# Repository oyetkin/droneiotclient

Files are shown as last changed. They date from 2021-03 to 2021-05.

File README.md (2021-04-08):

# droneiotclient

## Overview

This is the client end of a system designed to measure sensor data from a set of "Data Loggers" deployed in the field, retrieve the sensor data from a "Data Collector" device, and then process and use the data. The system contains 4 main items:

1. esp32_sleep: This code is for the Data Logger. The device is meant to include an ESP32 microcontroller, an SSD1306 display screen, a BME280 temperature/pressure/humidity sensor, and an IR receiver. The device consumes very low power so that it can last for weeks on battery power alone. It wakes up on a configurable interval to collect data, stores that data, and goes back to sleep. When the Data Collector device sends an IR signal to the device, it wakes up, sends its data using point-to-point WiFi (ESP-Now), and goes back to sleep.
The device also has a second Wifi mode, which can be toggled using a push button. In this mode, the device wakes up, connects to a WiFi network, and posts its data to a server.  

2. esp32_receiver. This code is for the Data Receiver. It is also meant to be used with an ESP32 device. The receiver uses a 38kHz-modulated infrared signal to wake the Data Logger when one button is pressed. It receives the Logger's data using ESP-Now point-to-point WiFi. It stores data from many sensors, and when it is in range of a WiFi network, you can push another button to make it upload its data. 

3. You'll need a server to collect and store data from the sensors. An open-source server that is compatible with this project available here: https://github.com/oyetkin/droneiotserver

4. Demo notebook. There are myriad ways to use and store the data, but we've created one sample project. It displays the locations of some sensors, and also creates a heatmap of some other sensors. Depending on what data is currently on the server, this demo script may fail to display data, but it should be easy to edit it to display whatever data is on the server.

## Quick start

1. Build the Data Logger and Data Receiver, following the schematic diagrams in the repository. There's also a tutorial article with more details on components and wiring. 
2. Clone this repo. In both esp32_receiver and esp32_sleep, edit the lines of code for your server URL and your WiFI ssid and password. In esp32_sleep, edit the lines of code for your latitude, longitude, and device name. 
3. Clone and run the server repo here: https://github.com/oyetkin/droneiotserver
4. Upload the esp32_receiver and esp32_sleep code to their respective devices. Set the Data Logger to Wifi Mode using one of the two buttons if you want it to upload data directly, or set it to Trigger Mode if you want to collect data through the receiver. 
5. Run the Demo ipy notebook to visualize your data. 

Read the tutorial for a more detailed introduction. See the server repo for more details on how to retrieve data. 

## File guide

1. Tutorial article, schematic
2. PCB
  Bill of materials for PCB
3. code

# Ideas for future developers...

There are a lot of things that can be done to make this device work better. Here are some ideas:
1. Currently, the Data Logger tells the Data Collector the time interval between its data, and the time since the last measurement. The Data Collector can use this to figure out what time each of the data points were recorded. However, this only works if you never miss a measurement. If the Logger fails to record a measurement today, it will record tomorrow's measurement in the spot meant for today, which messes up the timing. To fix this, you could record a "gap" or "blank" whenever you miss a measurement. To do this, you'd have to edit the data protocol to reserve a specific byte pattern as NaN. For instance, you could write 0xFFFF (which is currently the maximum value of a measurement) whenever you want to write a "blank," and make sure the Data Collector knows that 0xFFFF means "blank," not the max value. 
2. If the device loses power, it'll lose all its memory. This is a weakness for applications where the sensor needs to log data in harsh conditions (such as low temperature or being moved around or dropped). You could write to PROGMEM instead of the RTC memory. 
3. The device currently works on an ESP-32 Dev Board. The board has a voltage regulator for 5V --> 3V3, and an LED that's always on. That takes a whole lot of power! To achieve the low-power modes this design is meant for, you can redesign the device to work on the bare ESP32 chip instead of the Dev module.
4. In this vein, you could use a transistor, controlled by the ESP32, to control power to other devices. Before putting the ESP32 to sleep, you'd switch the transistor off so that the other devices don't consume any power when not needed. You'd want to pull the base low and use a bigger resistor to limit the current drain associated with the transistor itself. 
5. Also, the OLED and the Serial Monitor are slow and power-inefficient. You could remove the print statements and delay()s associated with using these displays in order to spend less time and power awake.

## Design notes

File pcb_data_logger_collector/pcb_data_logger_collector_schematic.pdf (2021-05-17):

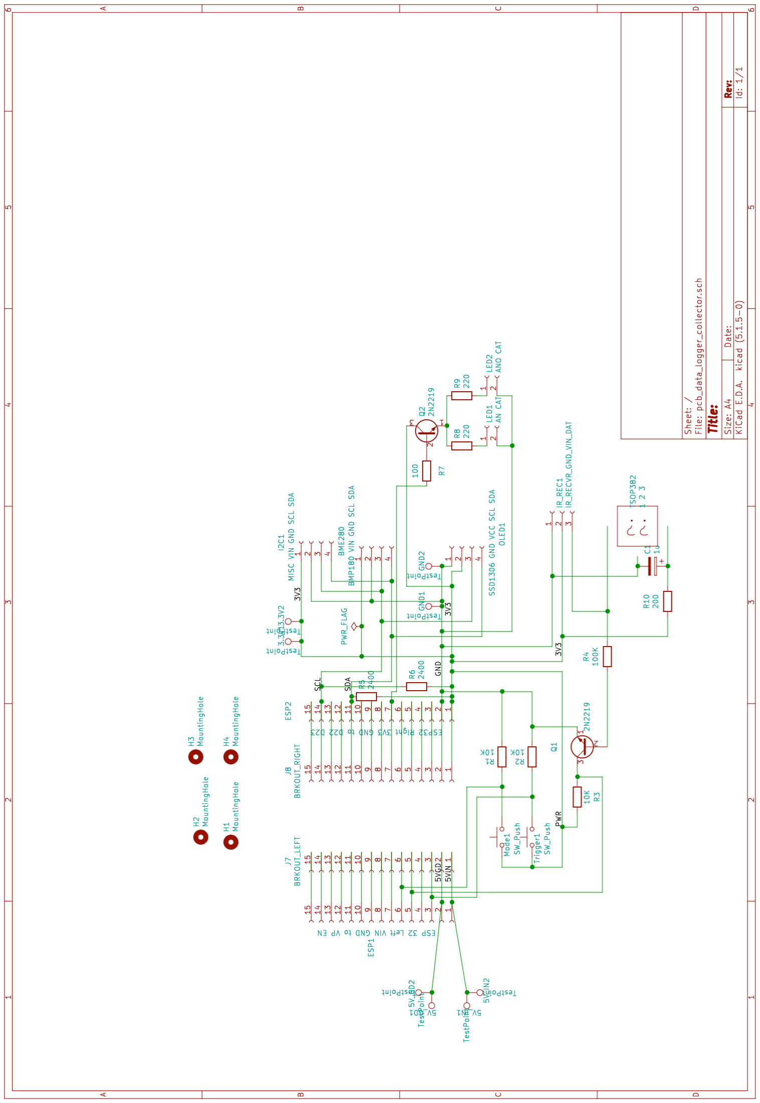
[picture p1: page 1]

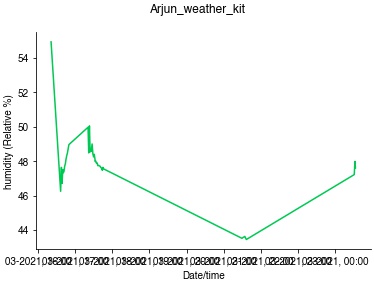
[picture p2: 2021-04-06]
data_vis_demo/graph_images/Arjun_weather_kit_humidity.jpg

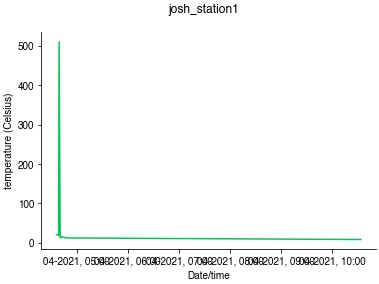
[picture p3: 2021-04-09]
data_vis_demo/graph_images/josh_station1_temperature.jpg

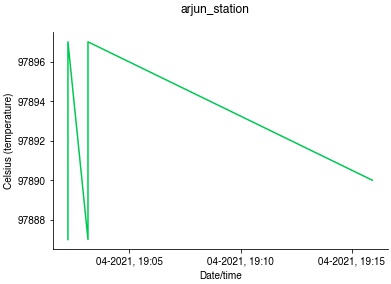
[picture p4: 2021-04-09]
data_vis_demo/graph_images/arjun_station_Celsius.jpg

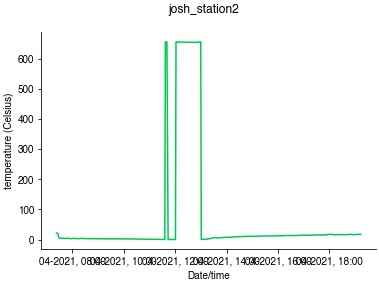
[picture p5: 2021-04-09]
data_vis_demo/graph_images/josh_station2_temperature.jpg

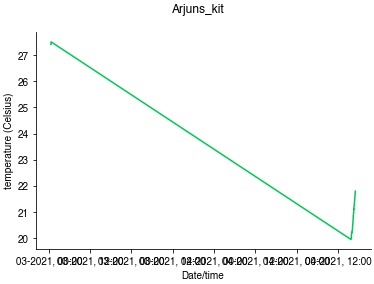
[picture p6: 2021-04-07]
data_vis_demo/graph_images/Arjuns_kit_temperature.jpg

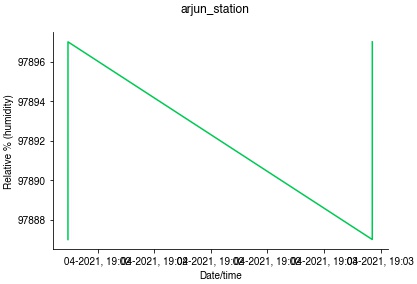
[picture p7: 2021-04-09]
data_vis_demo/graph_images/arjun_station_Relative %.jpg

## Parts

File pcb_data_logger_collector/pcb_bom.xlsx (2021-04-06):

 | Part | Key Specs | Quantity | Order Link | Notes
1 | Female Headers, I2C | 1x4, 2.54mm spacing | 2 | https://www.digikey.com/en/products/detail/sullins-connector-solutions/PPTC041LFBN-RC/810144
2 | Female Headers, ESP | 1x15, 2.54mm spacing | 2 | https://www.digikey.com/en/products/detail/sullins-connector-solutions/PPTC151LFBN-RC/810153
3 | Female Header, IR Receiver | 1x3, 2.54mm spacing | 1 | https://www.digikey.com/en/products/detail/sullins-connector-solutions/PPTC031LFBN-RC/810143
4 | Transistor, logic inverting and 38KHz modulation | SOT-23 package | 2 | https://www.digikey.com/en/products/detail/diodes-incorporated/ZXTN07045EFFTA/1557734 | SOT-23 package is not widely used; can switch if needed
5 | Resistors, button and other pullup | 10K Ohm, 0805 package | 3 | https://www.digikey.com/en/products/detail/bourns-inc/CR0805-FX-1002ELF/3593209
6 | Resistors, I2C Pullup | 2.4K Ohm, 0805 package | 2 | https://www.digikey.com/en/products/detail/bourns-inc/CR0805-FX-2401ELF/3784778
7 | Resistors, logic inverter | 100K Ohm, 0805 package | 1 | https://www.digikey.com/en/products/detail/te-connectivity-passive-product/CRG0805F100K/2380829
8 | Resistors, IR LED | 220 Ohm, 0805 package | 2 | https://www.digikey.com/en/products/detail/bourns-inc/CR0805-FX-2200ELF/3784749
9 | Resistors, IR Receiver | 200 Ohm, 0805 package | 1 | https://www.digikey.com/en/products/detail/bourns-inc/CR0805-FX-2000ELF/3784732
10 | Resistors, LED driver | 100 Ohm, 0805 package | 1 | https://www.digikey.com/en/products/detail/koa-speer-electronics-inc/RK73G2ATTD1000D/13576043
11 | Polarized Capacitor, IR Receiver | Tantalum, 1.25 x 1.05mm pads | 1 | https://www.digikey.com/en/products/detail/avx-corporation/F981C105MMA/4005059 | This has a very long button. One with a short button: https://www.digikey.com/en/products/detail/apem-inc/MJTP1138ALTR/1795455
12 | Momentary Button (Mode, Trigger) | 1 Pole 1 throw, 6x6mm | 2 | https://www.digikey.com/en/products/detail/apem-inc/MJTP1138BTR/1795451 | There is no footprint so you're not limited
13 | IR LED | 950nm IR emitter | 2 | https://www.digikey.com/en/products/detail/osram-opto-semiconductors-inc/SFH-4545/2205955 | Can pick any part, but make sure frequency matches PWM modulation frequency in the code. Use 382, not 392 (pinouts are different)
14 | TSOP382X Photodiode | 950 nm, 38kHz | 1 | https://www.digikey.com/en/products/detail/vishay-semiconductor-opto-division/TSOP38238/1681362

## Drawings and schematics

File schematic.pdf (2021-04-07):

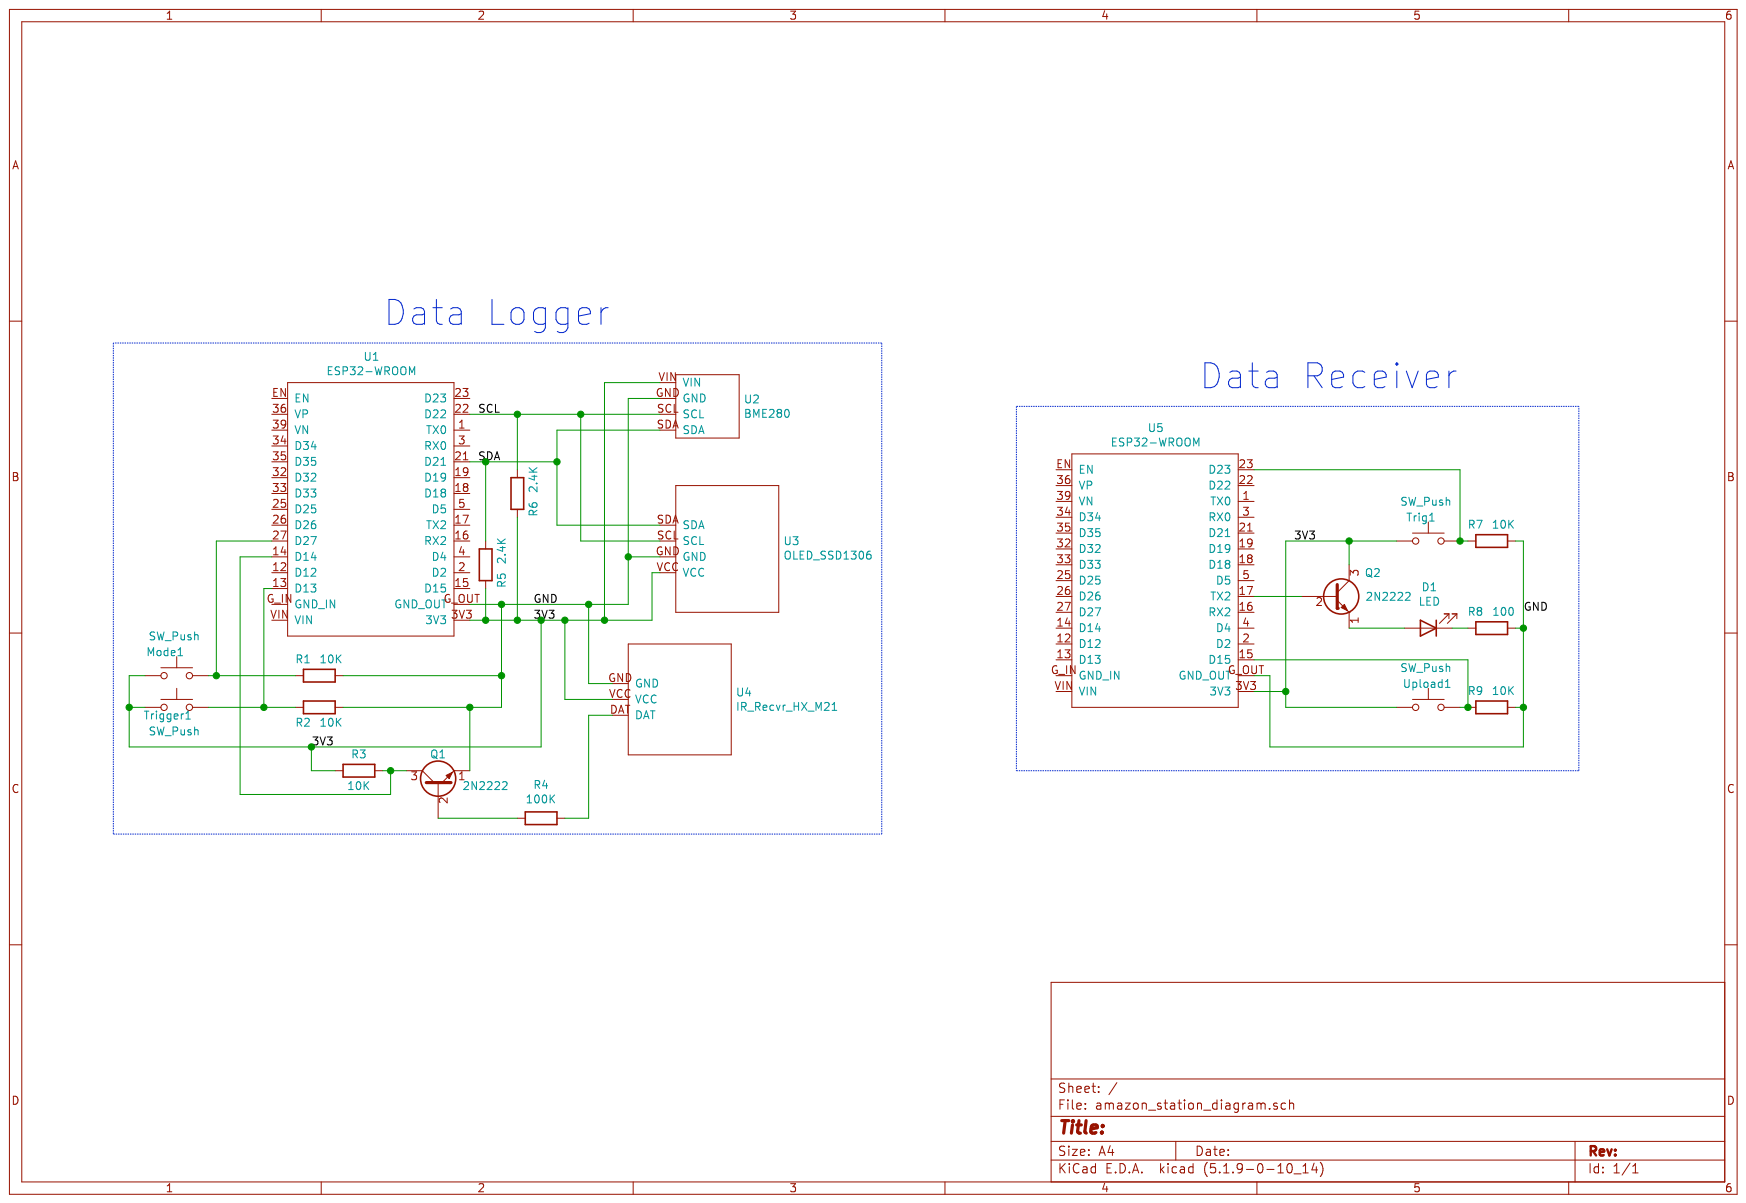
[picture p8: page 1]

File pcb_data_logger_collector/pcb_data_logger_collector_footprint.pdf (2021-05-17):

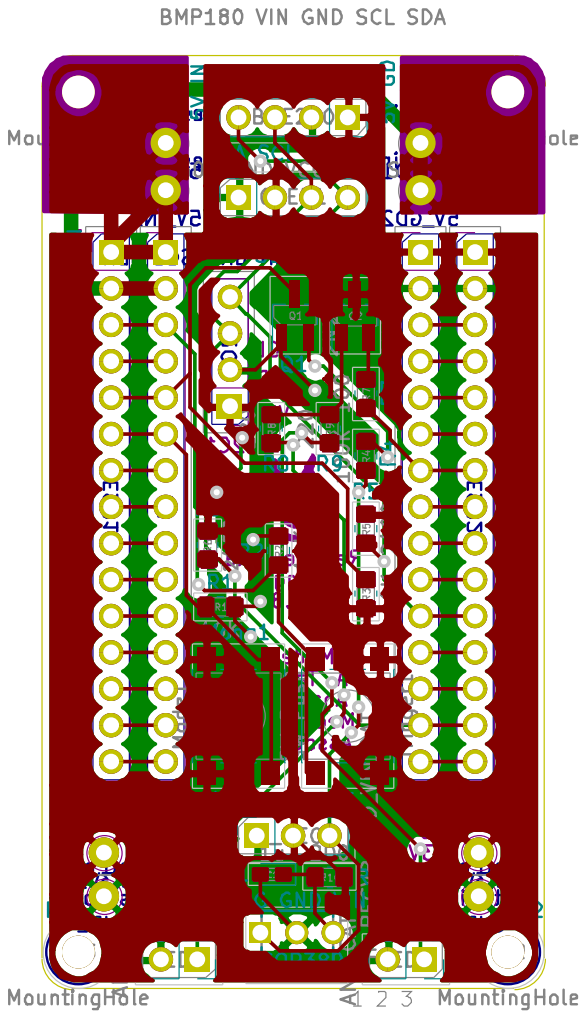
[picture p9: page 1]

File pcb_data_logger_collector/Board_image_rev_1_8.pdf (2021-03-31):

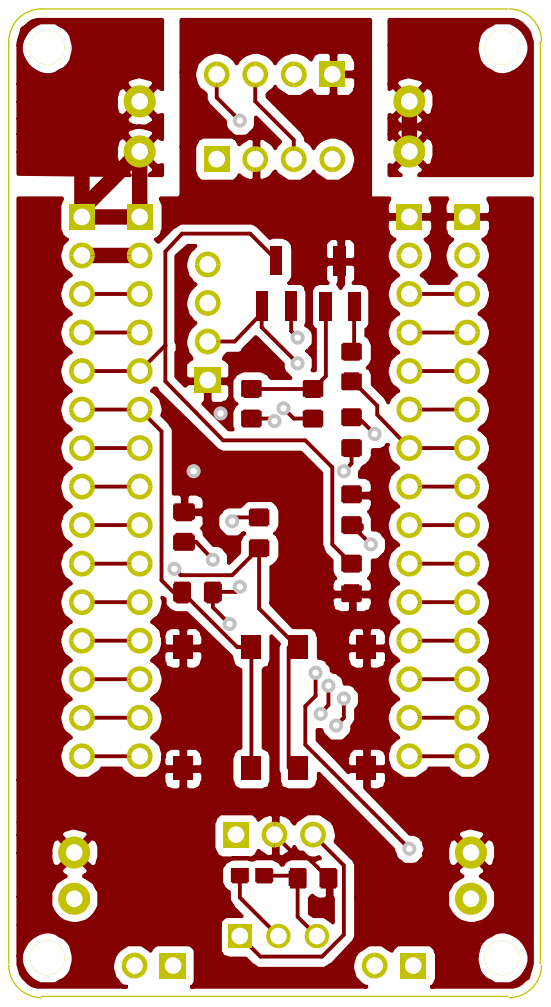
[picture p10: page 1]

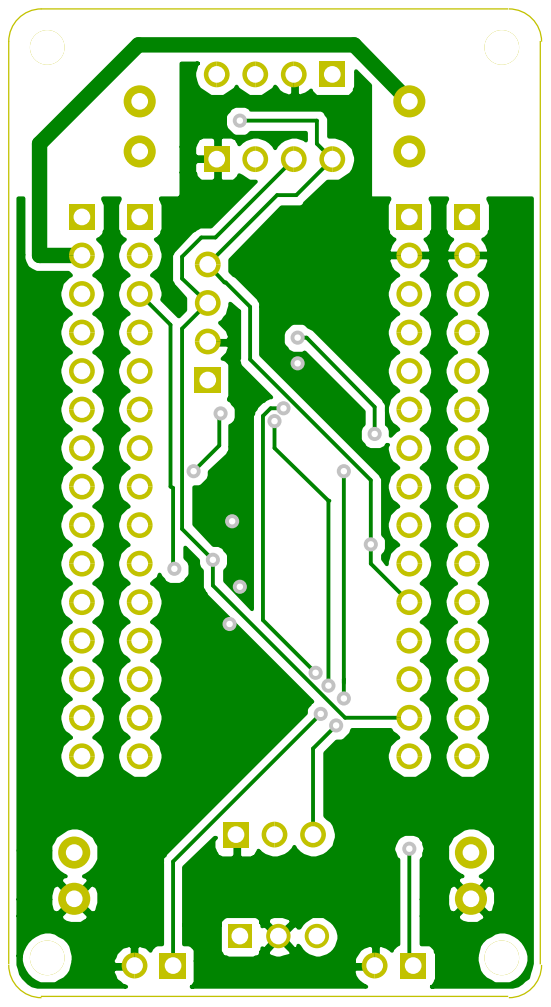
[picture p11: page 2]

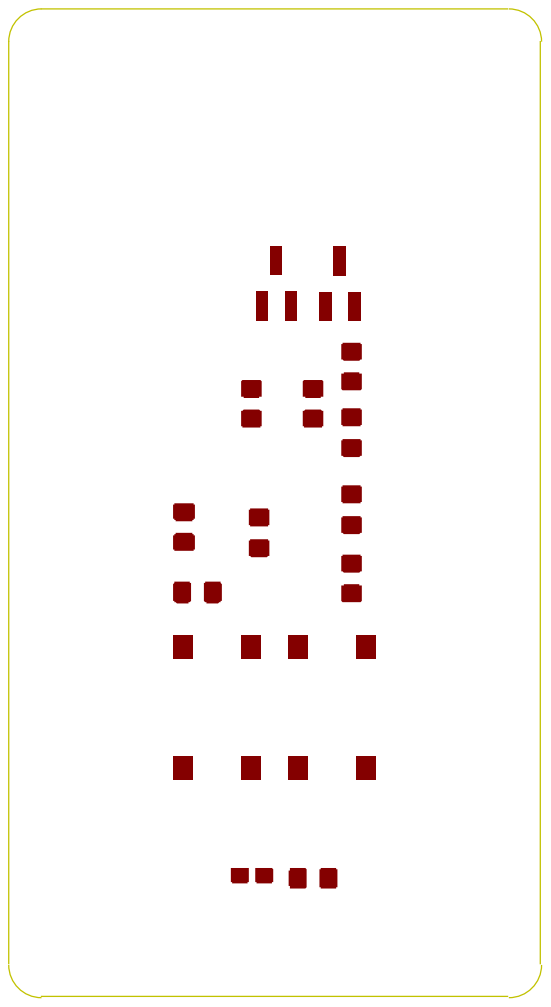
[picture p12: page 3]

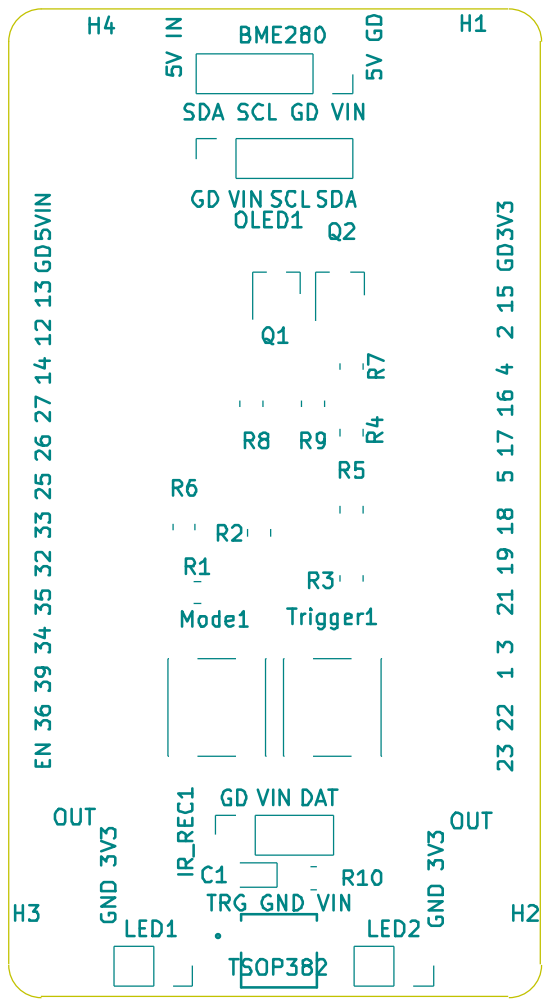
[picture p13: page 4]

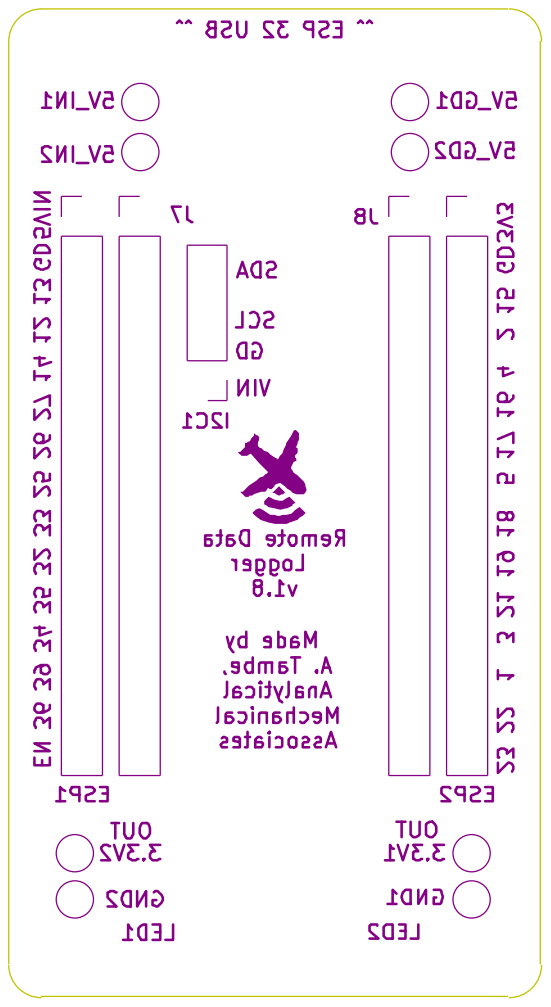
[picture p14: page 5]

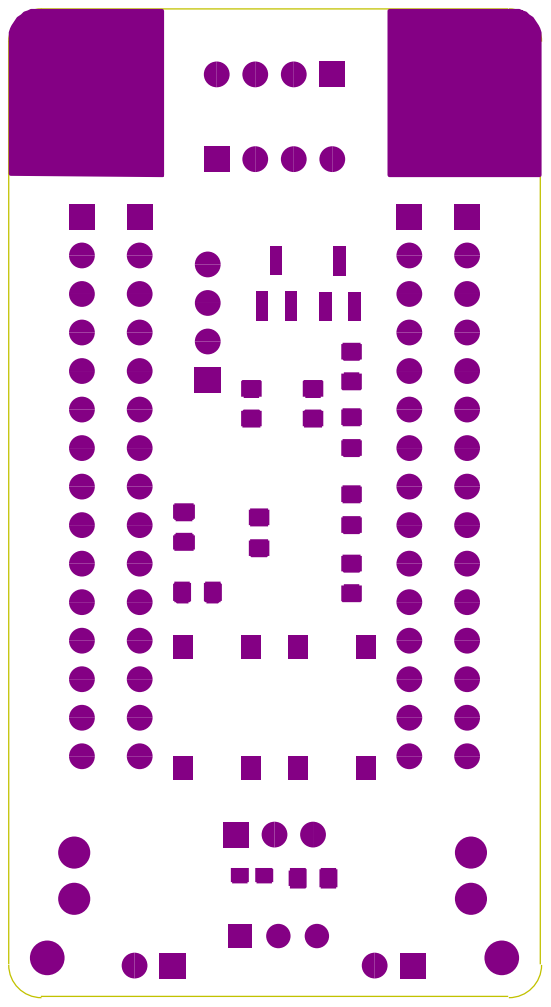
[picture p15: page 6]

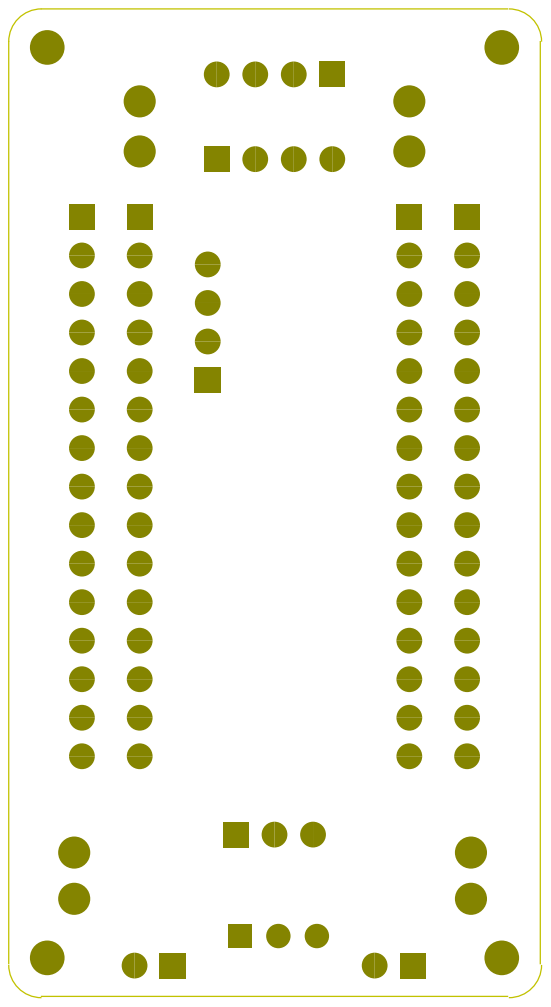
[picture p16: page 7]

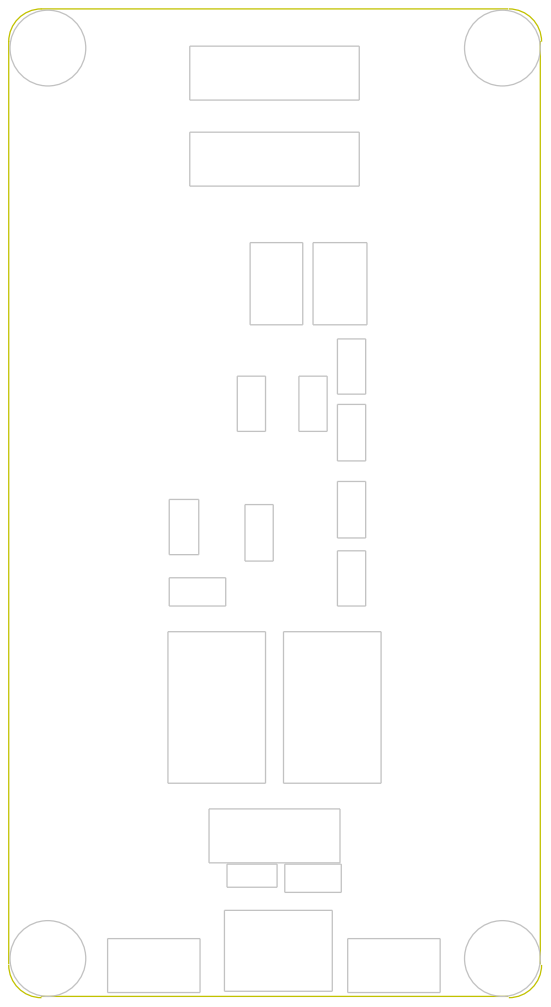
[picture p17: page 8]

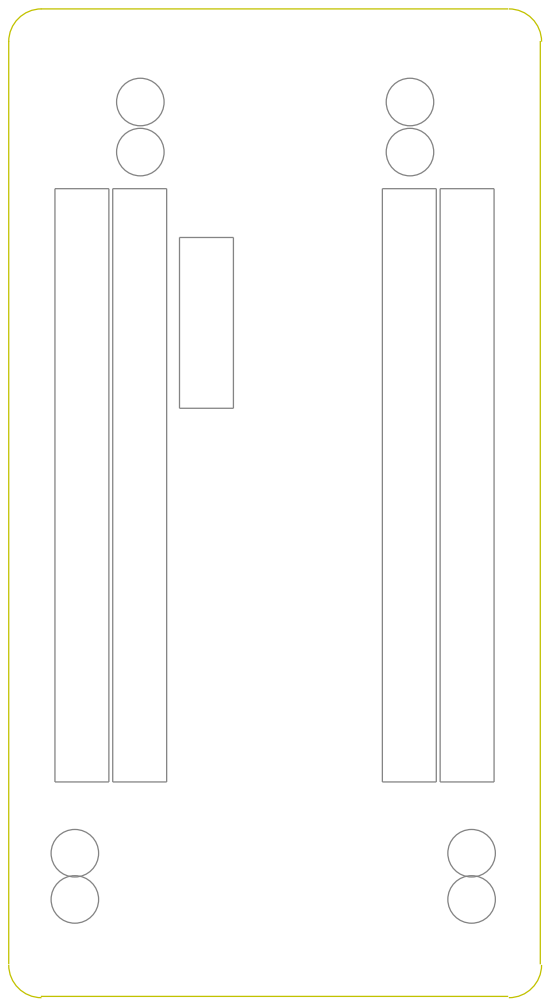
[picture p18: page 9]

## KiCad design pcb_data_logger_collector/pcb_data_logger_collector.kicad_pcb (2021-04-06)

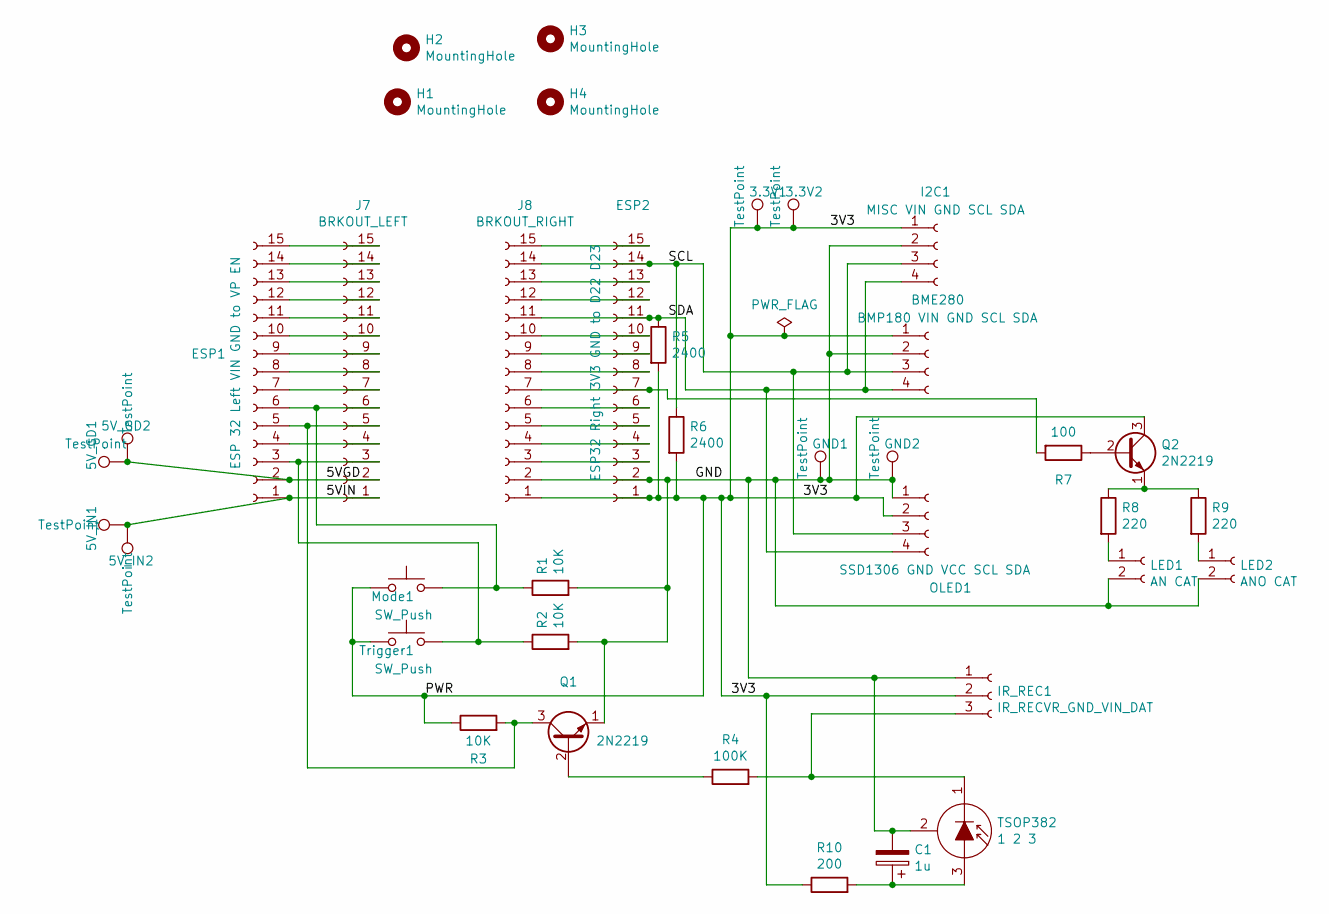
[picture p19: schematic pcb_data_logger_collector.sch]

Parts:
3.3V1, 3.3V2, 5V_GD1, 5V_GD2, 5V_IN1, 5V_IN2: TestPoint; TestPoint_THTPad_D2.0mm_Drill1.0mm
BME280: BMP180 VIN GND SCL SDA; PinSocket_1x04_P2.54mm_Vertical
C1: 1u; CP_EIA-1608-08_AVX-J_Pad1.25x1.05mm_HandSolder
ESP1: ESP 32 Left VIN GND to VP EN; PinSocket_1x15_P2.54mm_Vertical
ESP2: ESP32 Right 3V3 GND to D22 D23; PinSocket_1x15_P2.54mm_Vertical
GND1, GND2: TestPoint; TestPoint_THTPad_D2.0mm_Drill1.0mm
H1, H2, H3, H4: MountingHole; MountingHole_2.2mm_M2
I2C1: MISC VIN GND SCL SDA; PinSocket_1x04_P2.54mm_Vertical
IR_REC1: IR_RECVR_GND_VIN_DAT; PinSocket_1x03_P2.54mm_Vertical
J7: BRKOUT_LEFT; PinSocket_1x15_P2.54mm_Vertical
J8: BRKOUT_RIGHT; PinSocket_1x15_P2.54mm_Vertical
LED1: AN CAT; PinSocket_1x02_P2.54mm_Vertical
LED2: ANO CAT; PinSocket_1x02_P2.54mm_Vertical
Mode1: SW_Push; SW_Push_1P1T_NO_6x6mm_H9.5mm
OLED1: SSD1306 GND VCC SCL SDA; PinSocket_1x04_P2.54mm_Vertical
Q1, Q2: 2N2219; SOT-23_Handsoldering
R1, R2, R3: 10K; R_0805_2012Metric_Pad1.20x1.40mm_HandSolder
R4: 100K; R_0805_2012Metric_Pad1.20x1.40mm_HandSolder
R5, R6: 2400; R_0805_2012Metric_Pad1.20x1.40mm_HandSolder
R7: 100; R_0805_2012Metric_Pad1.20x1.40mm_HandSolder
R8, R9: 220; R_0805_2012Metric_Pad1.20x1.40mm_HandSolder
R10: 200; R_0805_2012Metric_Pad1.20x1.40mm_HandSolder
TSOP382: 1 2 3; XDCR_TSOP38238
Trigger1: SW_Push; SW_Push_1P1T_NO_6x6mm_H9.5mm

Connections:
/3V3: 3.3V1.1, 3.3V2.1, BME280.1, ESP2.1, I2C1.1, IR_REC1.2, J8.1, Mode1.1, OLED1.2, Q2.3 (C), R3.1, R5.2, R6.2, R10.1, Trigger1.1
/5VGD: 5V_GD1.1, 5V_GD2.1, ESP1.2, J7.2
/5VIN: 5V_IN1.1, 5V_IN2.1, ESP1.1, J7.1
/GND: BME280.2, C1.2, ESP2.2, GND1.1, GND2.1, I2C1.2, IR_REC1.1, J8.2, LED1.2, LED2.2, OLED1.1, Q1.1 (E), R1.2, R2.2, TSOP382.2 (C)
/SCL: BME280.3, ESP2.14, I2C1.3, J8.14, OLED1.3, R6.1
/SDA: BME280.4, ESP2.11, I2C1.4, J8.11, OLED1.4, R5.1
unnamed: C1.1, R10.2, TSOP382.3 (A)
unnamed: ESP1.3, J7.3, R2.1, Trigger1.2
unnamed: ESP1.4, J7.4
unnamed: ESP1.5, J7.5, Q1.3 (C), R3.2
unnamed: ESP1.6, J7.6, Mode1.2, R1.1
unnamed: ESP1.7, J7.7
unnamed: ESP1.8, J7.8
unnamed: ESP1.9, J7.9
unnamed: ESP1.10, J7.10
unnamed: ESP1.11, J7.11
unnamed: ESP1.12, J7.12
unnamed: ESP1.13, J7.13
unnamed: ESP1.14, J7.14
unnamed: ESP1.15, J7.15
unnamed: ESP2.3, J8.3
unnamed: ESP2.4, J8.4
unnamed: ESP2.5, J8.5
unnamed: ESP2.6, J8.6
unnamed: ESP2.7, J8.7, R7.2
unnamed: ESP2.8, J8.8
unnamed: ESP2.9, J8.9
unnamed: ESP2.10, J8.10
unnamed: ESP2.12, J8.12
unnamed: ESP2.13, J8.13
unnamed: ESP2.15, J8.15
unnamed: IR_REC1.3, R4.2, TSOP382.1 (K)
unnamed: LED1.1, R8.2
unnamed: LED2.1, R9.2
unnamed: Q1.2 (B), R4.1
unnamed: Q2.1 (E), R8.1, R9.1
unnamed: Q2.2 (B), R7.1

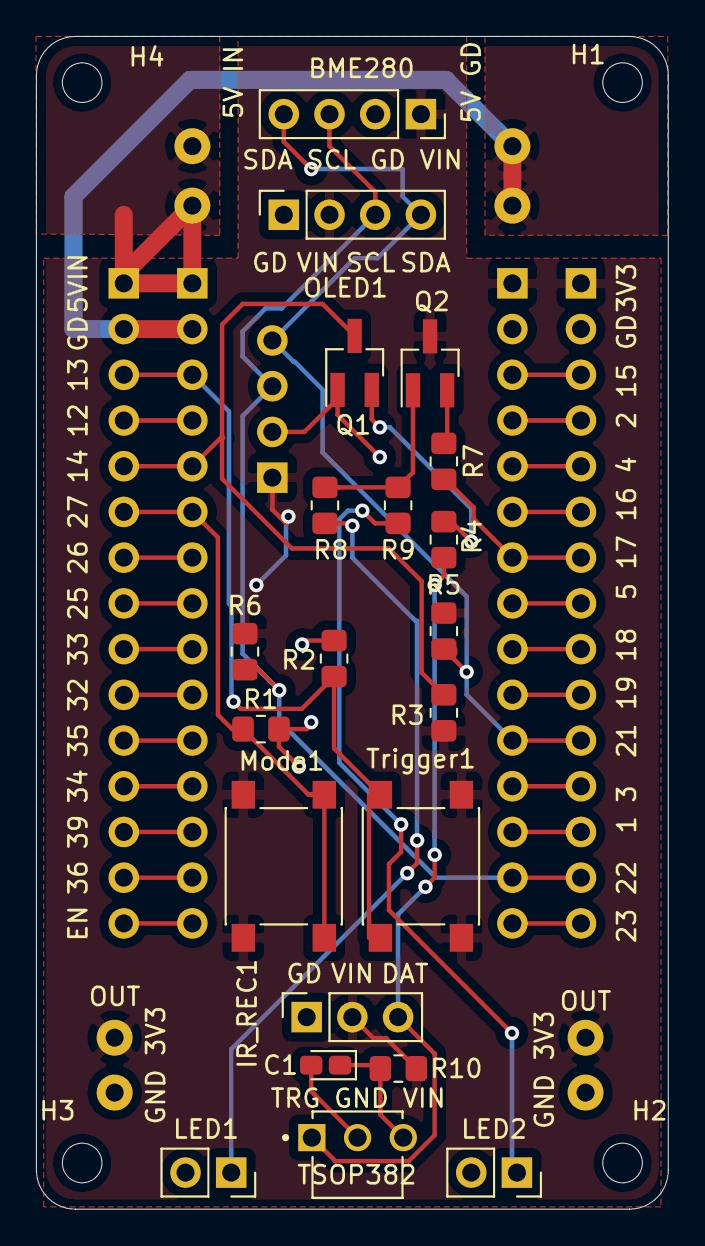
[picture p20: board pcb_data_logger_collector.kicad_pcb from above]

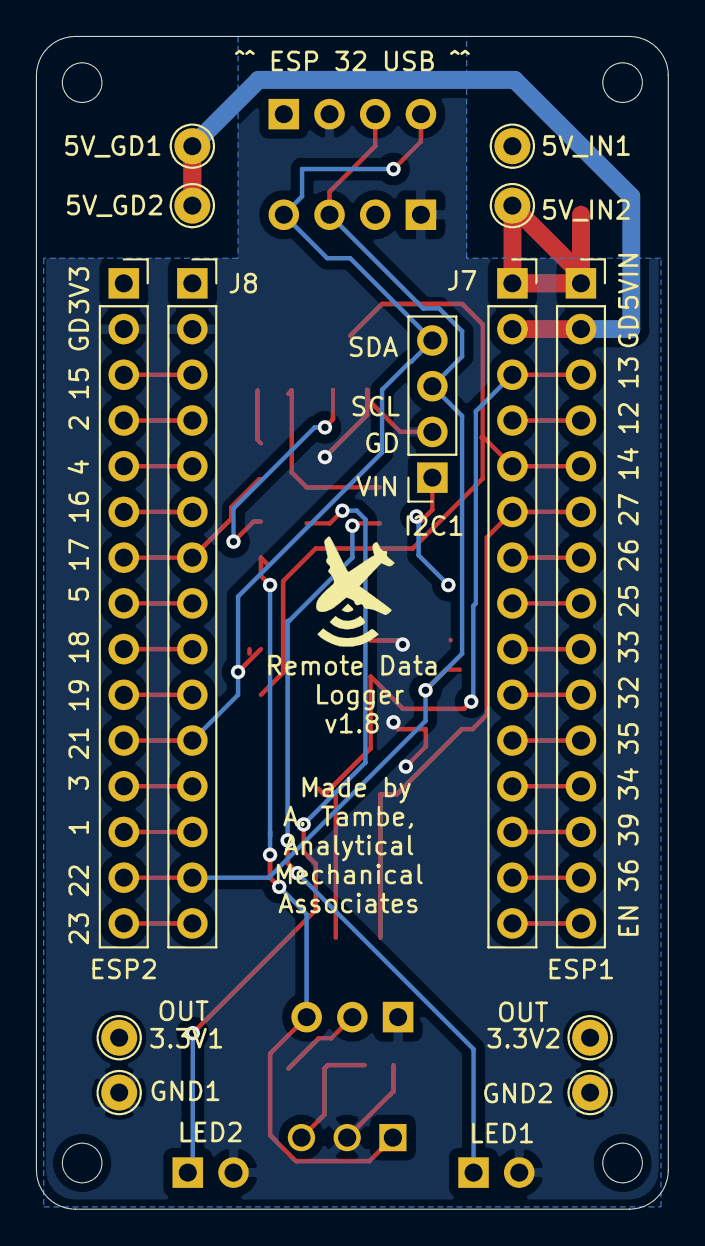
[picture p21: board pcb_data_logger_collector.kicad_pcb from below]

Board: 2 copper layers, 35.1 x 65.2 mm, 38 parts (13 on the bottom side), 37 nets.

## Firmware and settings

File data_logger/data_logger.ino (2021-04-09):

/*
 * Install the following libraries: 
 * "Wifi" (builtin)
 * "HTTP Client" (builtin on some devices)
 * "Adafruit BusIO"
 * "Adafruit Unified Sensor"
 * "ESP8266 and ESP32 OLED driver for SSD1306 displays"
 * "Adafruit BME280"
 * 
 * Author: Arjun Tambe, Analytical Mechanical Associates
 * Source: https://github.com/oyetkin/droneiotclient
 * 
 * Credit for some portions of code: 
 *    ESP-Now Demo by Arvind Ravulavaru <https://github.com/arvindr21>
 *    Getting the time: https://randomnerdtutorials.com/epoch-unix-time-esp32-arduino/
 */
#include <Wire.h>  
#include <WiFi.h>
#include "HTTPClient.h"
#include <Adafruit_BME280.h>
#include "SH1106Wire.h"
#include <time.h>
#include <esp_now.h>
#include <esp_clk.h>
#include <soc/rtc.h>
#include "driver/adc.h"
#include "esp_wifi.h"

// User should change these settings as needed
#define TIME_TO_SLEEP  20 //How long the device sleeps in between measurements
const char* ssid = "2firestar"; //your wifi network name
const char* password =  "sachin12"; //your wifi network password
const char* server = "https://api.is-conic.com/api/v0p1/sensor/batch"; //the URL to post to your server
const String device_name = "arjun_station"; //name of your device
float lat = 32.636462; //the latitude of the location of the device
float lon = -117.095660; //the latitude of the location of the device

//more advanced user settings
#define MAX_WIFI_RETRIES 30 //number of times to try connecting to wifi before giving up
#define DISPLAY_LEN 2000 //time to show OLED in millis
#define MODE_SELECT_LEN 4000 //time after a button press that the device returns to sleep
#define DEBOUNCE_TIME 400 //n millis to wait between 2 button presses

// PINOUTS
#define DEVICE_MODE_SELECT_PIN GPIO_NUM_27 //pin connected to mode select button
#define TRIGGER_PIN GPIO_NUM_14 //pin connected to remote trigger circuit
#define OLED_BUTTON GPIO_NUM_13 //pin connected to trigger button
#define WAKE_PIN_BITMASK 0x008006000 // must be equal to 2^MODE_SELECT + 2^OLED_BUTTON + 2^TRIGGER_PIN
#define ESP_NOW_CHANNEL 0 // can select any from 0-15

// OLED display settings
#define SCREEN_WIDTH 128 // OLED display width, in pixels
#define SCREEN_HEIGHT 64 // OLED display height, in pixels
#define OLED_RESET -1 // Reset pin # (or -1 if sharing Arduino reset pin)
#define POS_X_AXIS 5 //how far to draw x axis from the bottom margin, in pixels
#define POS_Y_AXIS 1 //how far to draw y axis from left margin
#define TITLE_X 10 // x coordinate where to draw graph title
#define TITLE_Y 6 // y coordinate where to draw graph title

//Addresses of the hardware devices. You shouldn't need to change these unless you get errors. 
#define OLED_ADDR 0x3c //use the 7-bit (not 8-bit) address for the OLED screen!
#define BME_ADDR 0x76 //default address of the BME sensor

//OTHER CONFIGURABLE
#define MAX_RECORDS 298 // Total N readings for each type of sensor data
#define RECORD_SIZE 2 //n bytes in a single record
#define PREAMBLE_LEN 2 //n bytes in the preamble for each packet
#define uS_TO_S_FACTOR 1000000ULL  // Conversion factor for micro seconds to seconds
#define CLOCK_RATE 150000 //Hz of the RTC clock. This is the default. Used to calculate time stuff. 

/// Code for the data structure. This should be in the receiver too

//This struct defines a category of measurement, like "temperature" or "humidity."
struct measurement {
  float min_value; //min recordable by senseor
  float resolution; //sensor resolution
  String unit; //e.g. "Celsius"
  String type; //e.g. "temperature"
  float graph_lower; //lowest value to display on graph
  float graph_upper; //highest value for graph
  String hardware_name; //optionally, hardware used to collect the measurement
};
typedef struct measurement Measurement;

//This is just a way to store 2 bytes together. There are methods to go between the 2-byte datatype to a float. 
struct twobyte {
  uint8_t high;
  uint8_t low;
};
typedef struct twobyte TwoByte;


/////////// Now, we'll set up the data that our sensor will record. 

//Create an instance of Measurement for each of the kinds of measurements your sensor will record
//the format is {min_value, increment, units, measurement name, graph_min, graph_max, hardware name}
Measurement pressure = {80000.0, 1.0, "Pa", "pressure", 90000, 110000, "BME280"};
Measurement temperature = {0.0, 0.01, "Celsius", "temperature", 15, 35, "BME280"};
Measurement humidity = {0, 0.01, "Relative %", "humidity", 30, 100, "BME280"};

//These arrays stores our data in byte (instead of float) form, to more efficiently use RTC memory.
//The RTC_DATA_ATTR prefix keeps this in RTC memory, so it won't get erased when the device sleeps
RTC_DATA_ATTR uint8_t hum_data[MAX_RECORDS*RECORD_SIZE];
RTC_DATA_ATTR uint8_t temp_data[MAX_RECORDS*RECORD_SIZE];
RTC_DATA_ATTR uint8_t pres_data[MAX_RECORDS*RECORD_SIZE];

//These arrays helps us iterate through the types without having to refer to each one specifically
Measurement measurements[3] = {temperature, humidity, pressure};
uint8_t* all_data[3] = {temp_data, hum_data, pres_data}; //Make sure to match the order of measurements!

//////// Finally, some housekeeping items...

//This server is used to get the real time
const char* ntpServer = "pool.ntp.org";

//Make global variables for our various devices. 
HTTPClient http;
SH1106Wire display(OLED_ADDR, SDA, SCL); //7 bit address only
Adafruit_BME280 bme;

//Global variable for a metadata array, used when sending ESP-Now data.
uint8_t metadata[ESP_NOW_MAX_DATA_LEN];

//Keeps track of the state of the device. 
RTC_DATA_ATTR bool device_mode_wifi = 0; //1 for wifi, 0 for trigger
RTC_DATA_ATTR int n_cycles_recorded = 0; //number of times you've recorded values from the sensors
RTC_DATA_ATTR int last_rtc_time = 0; //last reading of the rtc; update when you go to sleep. 

//for ESP Now - MAC address, channel, encrypt - set MAC address to either device or to broadcast address
esp_now_peer_info_t listener = {{0xFF, 0xFF,0xFF,0xFF,0xFF,0xFF}, ESP_NOW_CHANNEL, 0};
//esp_now_peer_info_t listener = {{0x9C, 0x9C, 0x1F, 0xC9, 0x50, 0x61}, ESP_NOW_CHANNEL, 0};


//////////////////////// Now for the actual code! /////////////////////////


void setup() {
  /*
   * This is the main function controlling what the device does. It opens the serial, checks
   * the cause of the wakeup, and decides to do based on the cause:
   *  -If it was the mode select pin, allow the user to change the mode
   *  -Otherwise, what we do depends on the mode we're in.
   *    -In Wifi mode:
   *      -if we woke from the trigger button, read the sensors, post to the server, and show the graph
   *      -if we woke from the timer, read and post but don't show the graph
   *      -if we're waking up the first time, display that on the OLED
   *    -In Trigger mode:
   *      -if we woke from the trigger button, immediately send the data using ESP-Now, and show the graph
   *      -if we woke from the timer, just read the sensors
   *      -if we're waking up for the first time, display that on the OLED.
   */
  Serial.begin(115200);
  delay(1000);

  //get and report wakeup cause, and print the mode the device is in.
  esp_sleep_wakeup_cause_t wakeup_reason = esp_sleep_get_wakeup_cause();
  print_wakeup_reason(wakeup_reason);
  Serial.println("Mode: " + mode_to_str(device_mode_wifi));
  int pin_triggered = get_wakeup_pin_number();
  
  if (pin_triggered == DEVICE_MODE_SELECT_PIN) { //The Mode Select button.
    mode_select();
  } else if (device_mode_wifi) {
    if (wakeup_reason == ESP_SLEEP_WAKEUP_EXT1) { //Either the IR Trigger,  or the Trigger Button
      if (!read_sensors()) {                      //If we fail to read the sensors, don't post and sleep instead.
        go_to_sleep();                            //Sleeping exits this code block. 
      }
      post_sensors();  //If desired, you can use the bool this returns to check if posting was successful.
      display_graph();
    } else if (wakeup_reason == ESP_SLEEP_WAKEUP_TIMER) { //The timer
      if (!read_sensors()) { go_to_sleep(); }
      post_sensors();
    } else {                                      // Device booted up for the first time
      show_wakeup();
      if (!read_sensors()) { go_to_sleep(); }
      post_sensors();
    }
  } else {
    if (wakeup_reason == ESP_SLEEP_WAKEUP_EXT1) { //Either the IR Trigger,  or the Trigger Button
      ESPNowBroadcast();
      display_graph();
    } else if (wakeup_reason == ESP_SLEEP_WAKEUP_TIMER) { //The timer
      if (!read_sensors()) { go_to_sleep(); }
    } else {                                      // Device booted up for the first time
      show_wakeup();
      read_sensors();
    } 
  }
  go_to_sleep();
}

///////////////////////////Top level methods///////////////////////

void mode_select() {
  /*
   * Call when the device is woken by the mode select pin. Activates the OLED
   * and allows the user to select the mode. Exits after a few seconds idle.
   */
  Serial.println("Press to select mode, currently " + mode_to_str(device_mode_wifi));
  pinMode(DEVICE_MODE_SELECT_PIN, INPUT);

  init_display();
  display_mode();
  unsigned long start_time = millis();
  unsigned long debounce = millis();
  while (millis() - start_time <= MODE_SELECT_LEN) {
    //if button is pressed, change mode and restart timer
    if (digitalRead(DEVICE_MODE_SELECT_PIN) && millis() - debounce >= DEBOUNCE_TIME) {
      device_mode_wifi = 1 - device_mode_wifi;
      Serial.println("Button pressed. Mode is: " + mode_to_str(device_mode_wifi));
      display_mode();
      start_time = millis();
      debounce = start_time;
    }
  }
  //turn off the OLED display
  display.displayOff();
}

bool read_sensors() {
  /*
   * Read the sensor values and print to the serial. 
   * Returns true if read was successful. 
   */
  if (!bme.begin(BME_ADDR)) {
    Serial.println("Could not find a valid BME sensor!");
    return false;
  }
  Serial.println("Read sensors");
  delay(2000); //The sensor takes 2 seconds to read after we turn it on
  float curr_hum = bme.readHumidity();
  float curr_temp = bme.readTemperature();
  float curr_pres = bme.readPressure();
  if (isnan(curr_hum) || isnan(curr_temp) || isnan(curr_pres)) {
    Serial.println("Failed to read!");
    return false;
  } 
  //Save all the measurements. The function handles the conversion between floats and bytes for us. 
  save_float_to_buffer(curr_temp, temperature, temp_data, MAX_RECORDS*RECORD_SIZE);
  save_float_to_buffer(curr_hum, humidity, hum_data, MAX_RECORDS*RECORD_SIZE);
  save_float_to_buffer(curr_pres, pressure, pres_data, MAX_RECORDS*RECORD_SIZE);

  //Print readings to the serial
  Serial.println("Humidity (RH%): " + String(curr_hum));
  Serial.println("Temperature (C): " + String(curr_temp));
  Serial.println("Pressure (Pa): " + String(curr_pres));

  //update the last RTC reading so we'll know how long it's been since last measurement. used when sending ESP-Now data.
  last_rtc_time = rtc_time_get();
  //update number of measurements taken
  n_cycles_recorded ++;
  return true;
}

bool post_sensors() {
  /*
   * Call this when the sensor is booted by time. Activates a wifi connection, 
   * loads the sensors, gets their readings, and posts the data. 
   * 
   * Returns true if posting was successful.
   */
  if (connect_to_server()) { //Attempt to connect to server, and proceed only if successful
    configTime(0, 0, ntpServer);
  
    //Now get the last measurements from the data buffers
    float temp = last_float_from_data(temp_data, temperature);
    float hum = last_float_from_data(hum_data, humidity);
    float pres = last_float_from_data(pres_data, pressure);
  
    //Create a batch POST request from a series of 3 post strings. 
    String posts[3] = {create_post_string(temp, temperature, true, true, true), 
                        create_post_string(hum, humidity, true, true, true),
                        create_post_string(pres, pressure, true, true, true)};
    int response = http.POST(multi_post_string(posts, 3));
    if (response != 200) { //200 indicates post was successful. Any other value indicates an error.
      Serial.println("HTTP Post error");
    }
    http.end(); ///End the HTTP client. 
    return (response == 200); //Returns true if response is 200, else false.
  } else {
    return false;
  }
}

void ESPNowBroadcast() {
  /*
   * Send ESP Now data as a broadcast. This has the advantage that we 
   * don't need to know the receiving device's MAC address beforehand. 
   */
  InitESPNow();
  esp_now_add_peer(&listener);
  //Send each of the 3 data buffers.
  sendData(temp_data, temperature, 1);
  sendData(hum_data, humidity, 2);
  sendData(pres_data, pressure, 3);
}

void ESPNowToMac() {
  /*
   * Send ESP Now data to a specific, hard-coded MAC address.  This avoids the
   * time/power required to scan all wifi networks, but still checks that a device
   * is ready to listen, and can also listen for an ACK signal from the listener. 
   * 
   * Does not retry or handle pairing failure! 
   */
  InitESPNow();
  esp_now_register_send_cb(OnDataSent); //optional, tells you the status of each packet sent.
  if (listener.channel == ESP_NOW_CHANNEL) { //check for correct channel; add peer
    Serial.print("Listener Status: ");
    esp_err_t addStatus = esp_now_add_peer(&listener);
    if (debug_ESP_error(addStatus)) { //Check if adding was successful
      //Send each of the 3 data buffers
      sendData(temp_data, temperature, 1);
      sendData(hum_data, humidity, 2);
      sendData(pres_data, pressure, 3);
    } else {
      Serial.println("Listener pair failed!");
    }
  } else {
    Serial.println("Non matching listener channel!");
  }
}

void go_to_sleep() {
  /*
   * Send the device to sleep.
   */
  Serial.println("Going to sleep now");
  delay(1000); //wait a second before flushing the serial.
  Serial.flush(); 

  //turn off ADC and wifi
  adc_power_off();
  WiFi.mode(WIFI_MODE_NULL); 
  esp_wifi_stop();
  //Before we sleep, make sure to enable the device to wake up next time!
  esp_sleep_enable_timer_wakeup(TIME_TO_SLEEP * uS_TO_S_FACTOR); //timer wakeup
  esp_sleep_enable_ext1_wakeup(WAKE_PIN_BITMASK,ESP_EXT1_WAKEUP_ANY_HIGH); //pin wakeup
  esp_deep_sleep_start();
}


/////////////////////////// ESP METHODS /////////////////////////////////////

void sendData(uint8_t* a, Measurement m, uint16_t index) {
  /*
   * Send the array a on ESP Now in multiple packets because the max
   * packet size is only 250 bytes. 
   * 
   * index: the "Packet ID" preamble which is used in conjunction with MAC Address.
   */

  //First, send the metadata.
  Serial.println("Sending metadata");
  makeMetaData(m, index, MAX_RECORDS*RECORD_SIZE);
  esp_now_send(listener.peer_addr, metadata, ESP_NOW_MAX_DATA_LEN);

  //Continue until you've sent all the bytes in the data buffer
  int total_sent = 0; //bytes of how much data you've sent so far
  while (total_sent < MAX_RECORDS*RECORD_SIZE) {
    //N bytes of data we can send is the bytes remaining, capped at the max ESP-now length minus the preamble length
    int remaining = MAX_RECORDS*RECORD_SIZE - total_sent; //N bytes not yet sent in the buffer
    int data_len = min(ESP_NOW_MAX_DATA_LEN - PREAMBLE_LEN, remaining);
    Serial.println("Sending " + String(data_len) + " bytes of " + String(MAX_RECORDS*RECORD_SIZE));

    //create the actual packet to send: first 2 bytes are the preamble, the rest is just the array
    uint8_t to_send[ESP_NOW_MAX_DATA_LEN] = {0};
    memset(&to_send[0], index, sizeof(uint8_t)); // index number of the data
    memcpy(&to_send[PREAMBLE_LEN], &a[total_sent], data_len);
    esp_now_send(listener.peer_addr, &to_send[0], data_len + PREAMBLE_LEN); //amount to send is the amount of data plus the preamble!

    //To help see what we're sending, print out the first data point (after the preamble)
    TwoByte s = {to_send[2], to_send[3]};
    Serial.print("Sending "); Serial.println(twobyte_to_float(s, m));

    //Update how many bytes we've sent
    total_sent += data_len;
   }
}

uint8_t* makeMetaData(Measurement m, uint16_t index, int data_len) {
  /*
   * Send a metadata packet that includes the following info in the following order:
   *    2-byte ID preamble (2 byte int)
   *    Sensor name (32 chars)
   *    Lat and lon (two 4-byte floats)
   *    Measurement name (32 chars)
   *    Min measurement value (4-byte float)
   *    Resolution (4-byte float)
   *    Hardware name (32 chars)
   *    N packets of data (2-byte int)
   *    Number of seconds between each measurement (2-byte int)
   *    Number of seconds since last reading (2-byte int)
   *  It accomplishes this by memcpy'ing each piece of information in the respective
   *  positions. The receiver must contain code to read this metadata to function properly.
   *  
   *  index is an arbitrary number to separate different sets of data from each other. 
   *  
   *  data_len is the total number of bytes we will be sending after the metadata. 
   *  
   *  Remember that any changes to the structure of this metadata must also be reflected 
   *  in the collector code!
   */
  //Create all the parameters we'll be sending; they need to be char arrays instead of Strings
  const char* device_name_c = device_name.c_str();
  const char* measurement_type_c = m.type.c_str();
  const char* unit_c = m.unit.c_str();
  const char* hardware_name_c = m.hardware_name.c_str();
  //N packets is the total N bytes to send, divided by the bytes in each packet. Round up by adding 1 if the division isn't even.
  uint8_t n_packets = data_len/ESP_NOW_MAX_DATA_LEN + (data_len%ESP_NOW_MAX_DATA_LEN != 0);
  uint16_t time_interval = TIME_TO_SLEEP;
  uint16_t time_offset = getTimeSinceLast();
  
  int byte_pos = 0; //As we memcpy stuff into the metadata, increment this to see where the next field is

  // First is the preamble. It's a 2-byte int. 
  memset(&metadata[byte_pos], index, sizeof(uint16_t)); 
  byte_pos += sizeof(uint16_t);
  
  // Next, copy the device name string. This function handles special cases for us. 
  set_null_terminated_metadata_string(byte_pos, device_name_c, 32);
  byte_pos += 32;
  //Next, lat and lon floats
  memcpy(&metadata[byte_pos], &lat, sizeof(float)); // lat
  byte_pos += sizeof(float);
  memcpy(&metadata[byte_pos], &lon, sizeof(float)); // lon
  byte_pos += sizeof(float);
  //More strings. Call the same function as above.
  set_null_terminated_metadata_string(byte_pos, measurement_type_c, 32);
  byte_pos += 32;
  set_null_terminated_metadata_string(byte_pos, unit_c, 32);
  byte_pos += 32;
  memcpy(&metadata[byte_pos], &m.min_value, sizeof(float)); // min value
  byte_pos += sizeof(float);
  memcpy(&metadata[byte_pos], &m.resolution, sizeof(float)); // resolution
  byte_pos += sizeof(float);
  set_null_terminated_metadata_string(byte_pos, hardware_name_c, 32);
  byte_pos += 32;
  memcpy(&metadata[byte_pos], &n_packets, sizeof(uint8_t)); // n packets
  byte_pos += sizeof(uint8_t);
  memcpy(&metadata[byte_pos], &time_interval, sizeof(uint16_t)); // time interval
  byte_pos += sizeof(uint16_t);
  memcpy(&metadata[byte_pos], &time_offset, sizeof(uint16_t)); // time offset
  byte_pos += sizeof(uint16_t);

  
  Serial.println("Successfully created metadata");
}

void InitESPNow() {
  /*
   * Just initialize the ESP Now
   */
  WiFi.mode(WIFI_STA);
  //WiFi.disconnect(); //this is only necessary if you're directly switching from wifi to esp now
  if (esp_now_init() == ESP_OK) {
    Serial.println("ESPNow Init Success");
  } else {
    Serial.println("ESPNow Init Failed");
  }
}

void OnDataSent(const uint8_t *mac_addr, esp_now_send_status_t status) {
  /*
   * Use this to check if packets were sent successfully. Call it with 
   * esp_now_register_send_cb(OnDataSent) and this function will be called
   * every time you send a packet. 
   */
  char macStr[18];
  snprintf(macStr, sizeof(macStr), "%02x:%02x:%02x:%02x:%02x:%02x",
           mac_addr[0], mac_addr[1], mac_addr[2], mac_addr[3], mac_addr[4], mac_addr[5]);
  Serial.print("Last Packet Sent to: "); Serial.println(macStr);
  Serial.print("Last Packet Send Status: "); Serial.println(status == ESP_NOW_SEND_SUCCESS ? "Delivery Success" : "Delivery Fail");
}

bool debug_ESP_error(esp_err_t err) {
  /*
   * Just look at the error value and print a readable message corresponding to it
   */
  if (err == ESP_OK) {
    Serial.println("Successfully paired");
    return true;
  } else if (err == ESP_ERR_ESPNOW_NOT_INIT) {
    Serial.println("ESPNOW not Init.");
    return false;
  } else if (err == ESP_ERR_ESPNOW_ARG) {
    Serial.println("Invalid Argument");
    return false;
  } else if (err == ESP_ERR_ESPNOW_INTERNAL) {
    Serial.println("Internal Error");
    return false;
  } else if (err == ESP_ERR_ESPNOW_NO_MEM) {
    Serial.println("Out of memory");
    return false;
  } else if (err == ESP_ERR_ESPNOW_NOT_FOUND) {
    Serial.println("Peer not found.");
    return false;
  } else if (err == ESP_ERR_ESPNOW_FULL) {
    Serial.println("Peer list full");
    return false;
  } else if (err == ESP_ERR_ESPNOW_EXIST) {
    Serial.println("Peer Exists");
    return true;
  } else {
    Serial.println("Unknown error");
    return false;
  }
}

////////////////////////// DATA METHODS /////////////////////////////

void save_float_to_buffer(float v, Measurement m, uint8_t* a, int a_len) {
  /*
   * Given a float measurement, save it in the data buffer. 
   * 
   * Float: the float value measurement to save (e.g. 25.6, meaning 25.6 degrees C)
   * Measurement: the type of measurement (e.g. temperature - should be instantiated as a struct)
   * a: The data array you are storing the measurements in
   * a_len: Number of bytes in a (NOT the number of measurements!)
   * 
   * Converts to twoByte, then saves the twoByte to the buffer
   */

  TwoByte v_short = float_to_twobyte(v, m);
  save_bytes_to_buffer(a, v_short, a_len);
}
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
void loop() {}

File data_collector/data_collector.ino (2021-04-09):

/*
 * Notes...
 * 
 * 
 * Author: Arjun Tambe, Analytical Mechanical Associates
 * Source: https://github.com/oyetkin/droneiotclient
 * 
 * Credit for some portions of code: 
 *    ESP-Now Demo by Arvind Ravulavaru <https://github.com/arvindr21>
*/

#include <esp_now.h>
#include "WiFi.h"
#include "HTTPClient.h"

//Edit these!
const char* ssid = "2firestar"; //Name of your wifi network
const char* password =  "sachin12"; //Password for your wifi network
const char* server = "https://api.is-conic.com/api/v0p1/sensor/batch"; //URL for your server

//Pinouts and configurable
#define TRIGGER_PIN GPIO_NUM_16 //for the trigger button
#define LED_PIN GPIO_NUM_17 //output gpio for the led
#define UPLOAD_PIN GPIO_NUM_23 //button that activates uploading when pressed
#define MAX_WIFI_RETRIES 40 //number of times to try connecting to wifi before giving up
#define LED_ON_TIME 3000 //how long to turn on the IR LEDs in millis
#define MAX_SERIES 3 //maximum number of different data series we can read from (see below)

//Other stuff
#define CHANNEL 1 //esp now transmission channel, anything from 1-16
#define PWM_CHANNEL 1 //anything from 1-16
#define LED_FREQ 38000 //pwm modulation frequency, depends on data logger IR hardware
#define DUTY_CYCLE_RES 8 //keep at 8 bits, we don't need better resolution
#define INVALID_LOCATION -181.0 //an invalid lat/lon to use as a placeholder

//This MUST match the code in the data logger to accurately send metadata
#define RECORD_SIZE 2 //n bytes in a single record
#define PREAMBLE_LEN 2
#define MAX_RECORDS 298 // Max number of readings that each sensor could contain

//This struct defines a category of measurement, like "temperature" or "humidity."
struct measurement {
  float min_value; //min recordable by senseor
  float resolution; //sensor resolution
  String unit; //e.g. "Celsius"
  String type; //e.g. "temperature"
  String hardware_name; //optionally, hardware used to collect the measurement
  //The data logger version has graph lower and upper bounds, which we don't need here.
};
typedef struct measurement Measurement;

//One data_series contains metadata and data for a single measurement type. 
//For example, temperature data from one device and humidity data from the same device
//are considered two separate data_series. 
//We don't have to instantiate these ourselves - we'll use the metadata contained in packets to do that!
struct data_series {
  String series_id; //A unique ID (MAC address + a 2-byte preamble) used to identify packets
  String device_name; //Name of the data logger
  float lat; //coordinates of the logger
  float lon;
  Measurement m; //the type of measurement this data series tracks
  float* sensor_data; //contains the actual data for this data series
  int n_records_recd; //how many values the sensor_data array actually contains right now
};
typedef struct data_series dataSeries;

//Create an array containing ALL the data series
dataSeries all_data_series[MAX_SERIES];

//This is just a way to store 2 bytes together. There are methods to go between the 2-byte datatype to a float. 
struct twobyte {
  uint8_t high;
  uint8_t low;
};
typedef struct twobyte TwoByte;

//Number of different data series we've received so far
int n_series_received = 0;

//Fix this later...
#define POST_LENGTH 250 //number of characters in a single json-formatted post request
char batch_post[2 + MAX_RECORDS*POST_LENGTH];
HTTPClient http;


////////////////// begin the code    //////////////////////
void setup() {
  /*
   * Initialize the serial and configure the pinouts. 
   */
  Serial.begin(115200);
  delay(1000);

  pinMode(TRIGGER_PIN, INPUT);
  pinMode(LED_PIN, OUTPUT);

  //Used for PWM; set LED_FREQ to the desired freuqency
  ledcSetup(PWM_CHANNEL, LED_FREQ, DUTY_CYCLE_RES);
  ledcAttachPin(LED_PIN, PWM_CHANNEL);
}

void loop() {
  /*
   * Waits for one of the two buttons to be pressed. The first button makes it activate the LED,
   * and listen for ESP-Now packets. The other makes it upload its data to the server. 
   */
  bool trigger = false;
  bool upload = false;
  while(!trigger && !upload) {              //stay in this loop until one of the buttons is pressed
    delay(10);
    trigger = digitalRead(TRIGGER_PIN);
    upload = digitalRead(UPLOAD_PIN);
  }
  if (trigger) {       // if it was the trigger button, then prepare for ESP Now and fire the IR LED
    Serial.println("Trigger pressed!");
    //When data is received, it calls the callback function "OnDataRecv." 
    setUpESPNow();
    sendIRTrigger();
  } else if (upload) {       //If it was the upload button, connect to the wifi and upload your data
    Serial.println("Upload pressed!");
    uploadData();
  }
}

//////////////////// High level functions ///////////////////////

void sendIRTrigger() {
  /*
   * Simply turn the LED on, and turn it back off after a few seconds
   * The PWM frequency of the LED is configured in setup(), and must match
   * the hardware of the data logger's IR receiver.
   */
  //Write a 50% duty cycle (a square wave that's HIGH half the time) by dividing the 
  //maximum resolution value (2^DUTY_CYCLE_RES) by 2. 
  ledcWrite(PWM_CHANNEL, pow(2, DUTY_CYCLE_RES-1));
  delay(LED_ON_TIME);
  ledcWrite(PWM_CHANNEL, 0); //write 0% duty cycle, aka off
}


void uploadData() {
  /*
   * Upload all data to the server. Iterates through each of the series we have, 
   * creates a Post string for that series, and posts it. 
   * 
   * If a Series has been instantiated, but the data inside that Series remains empty then
   * there may be issues!
   */
  if (connect_to_server()) {
    for (int i=0; i<n_series_received; i++) {
      post_all_records(all_data_series[i]);
      int response = http.POST(batch_post);
      if (response != 200) {
        Serial.print("HTTP Post error "); Serial.println(response);
      } else {
        Serial.println("Successfully posted.");
      }
    }
    http.end();
  }
}
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

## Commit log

2021-03-02 Initial Arduino code to read barometer and pressure sensor with Arduino
2021-03-04 added requirements and start of arduino sketch
2021-03-04 Added demo script to upload a temperature measurement using the arduino sketch in this repository. It will have to be modified for the particular port on the machine that its running on which represn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
2021-03-04 print all in sensor_prototype
2021-03-08 Fully working sensor, oled, and post
2021-03-08 visualize sensor location from json
2021-03-08 ESP32 demo and visualization ready
2021-03-09 Added pressure sensor and testing IR
2021-03-11 sleep with gpio and timer wake
2021-03-16 swapped to work with new OLED and BME 280
    [esp8266_demo.ino]
2021-03-16 added mode switch
2021-03-19 added receiver trigger on button press
2021-03-23 add pcb and new visualization
    [amazon_ready_station.kicad_pcb, amazon_ready_station.sch, amazon_ready_station.step]
2021-03-23 hackathon pcb semi-final draft
    [amazon_ready_station.kicad_pcb, amazon_ready_station.sch]
2021-03-23 fixed heatmap code
2021-03-24 chamfer edges, fix oled orientation bug
    [amazon_ready_station.kicad_pcb]
2021-03-24 update pcb and add time slider to virginia demo
    [amazon_ready_station.kicad_pcb, amazon_ready_station.sch, amazon_ready_station.step]
2021-03-24 added artwork, edited silkscreen
    [amazon_ready_station.kicad_pcb, amazon_ready_station.sch, amazon_ready_station.step]
2021-03-25 fixed heatmap bug
2021-03-26 added screw holes and edited Pwr In plates
    [amazon_ready_station.kicad_pcb, amazon_ready_station.sch, amazon_ready_station.step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]
2021-03-26 changed to mode select momentary button instead of switch
2021-03-31 pcb with receiver components
    [amazon_ready_station.kicad_pcb, amazon_ready_station.sch]
2021-03-31 small revisions
    [amazon_ready_station.kicad_pcb]
2021-03-31 update ipy notebook, fix receiver esp-now bug
    [spoof_sensors.ino]
2021-03-31 moved LED to bottom, added IR Rec circuit on board
    [amazon_ready_station.kicad_pcb, amazon_ready_station.sch]
2021-04-01 added PCB BOM, added graphs in map to the virginia demo
    [amazon_ready_station.kicad_pcb, station_bom.csv, station_bom.xlsx]
2021-04-02 Added tutorial article, edited demo code, added schematic
    [amazon_ready_station.kicad_pcb, amazon_station_diagram.kicad_pcb, amazon_station_diagram.sch]
2021-04-05 process data from multiple sensors at a time
    [amazon_station_diagram.sch]
2021-04-07 fixed heatmap
2021-04-07 added receiver schematic
    [amazon_station_diagram.sch]
2021-04-07 rename and cleanup
    [pcb_bom.xlsx, pcb_data_logger_collector.kicad_pcb, pcb_data_logger_collector.sch]
2021-05-17 Footprint and schmatic diagrams expored for convenience
